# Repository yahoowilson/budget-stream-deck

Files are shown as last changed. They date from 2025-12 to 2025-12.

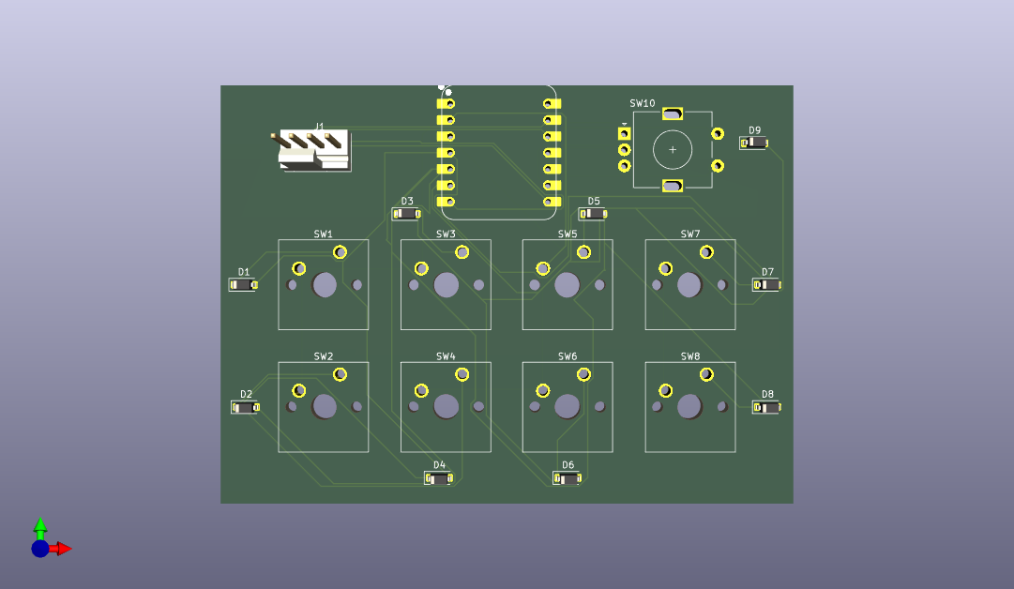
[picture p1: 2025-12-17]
PCB/controller.png

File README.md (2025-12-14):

# Logan's Budget Stream Deck
This is the first custom project that I made entirely myself with blueprint. I wanted a stream deck but did not want to pay $150, so I thought it would be cool to try and make my own. So here is my attempt at a "budget" stream deck with 8 switches, a rotary encoder and an oled screen. all programmable. The BOM is viewable below or downloadable in excel or pdf format to access the links.




entire deck case

Bill of Materials (also in .xlsx or .pdf format above)


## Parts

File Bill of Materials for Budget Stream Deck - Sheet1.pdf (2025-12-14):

Item | Price | Quantity | Shipping Cost | Manufacturer | Total Cost
XIAO RP 2040 | $3.99 | 1 pcs | $6.20 | seeedstudio.com | $10.19
MX Switches | $2.80 | 10 pcs | $4.90 | mechanicalkeyboards.com $7.70
Hotswap Sockets | $1.10 | 10 pcs | $0.00 | mechanicalkeyboards.com $1.10
Blank Keycaps | $7.00 | 8 pcs | $0.00 | mechanicalkeyboards.com $7.00
Diodes | $4.95 | 100pcs | $0.00 | adafruit.com | $4.95
Rotary Encoder with Dial knob$5.70 | | 1 pcs | $5.42 | adafruit.com | $11.12
OLED display | $6.99 | 1 pcs | $0.00 | amazon.com | $6.99
1x4 pin header | $6.99 | 1 pcs | $0.00 | amazon.com | $6.99
PCB | $2 | 1pcs | $5.30 | JLCPCB.com | $5
| $41.52 | | $21.82 | | 61.04

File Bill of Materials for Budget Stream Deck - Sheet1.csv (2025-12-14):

Item | Price | Quantity | Shipping Cost | Manufacturer | Total Cost
XIAO RP 2040 | $3.99 | 1 pcs | $6.20 | seeedstudio.com | $10.19 | x
MX Switches | $2.80 | 10 pcs | $4.90 | mechanicalkeyboards.com | $7.70 | x
Hotswap Sockets | $1.10 | 10 pcs | $0.00 | mechanicalkeyboards.com | $1.10 | x
Blank Keycaps | $5.95 | 8 pcs | $0.00 | mechanicalkeyboards.com | $5.95 | x
Diodes | $4.95 | 100pcs | $0.00 | adafruit.com | $4.95 | x
Rotary Encoder with Dial knob | $5.70 | 1 pcs | $5.42 | adafruit.com | $11.12 | x
OLED display | $6.99 | 1 pcs | $6.99 | amazon.com | $6.99 | x
1x4 pin header | $11.99 | 1 pcs | 0 | amazon.com | $11.99 | x
PCB | $2 | 1pcs | $5.30 | JLCPCB.com | $5 | x
 | $45.47 |  | $28.81 |  | $74.28

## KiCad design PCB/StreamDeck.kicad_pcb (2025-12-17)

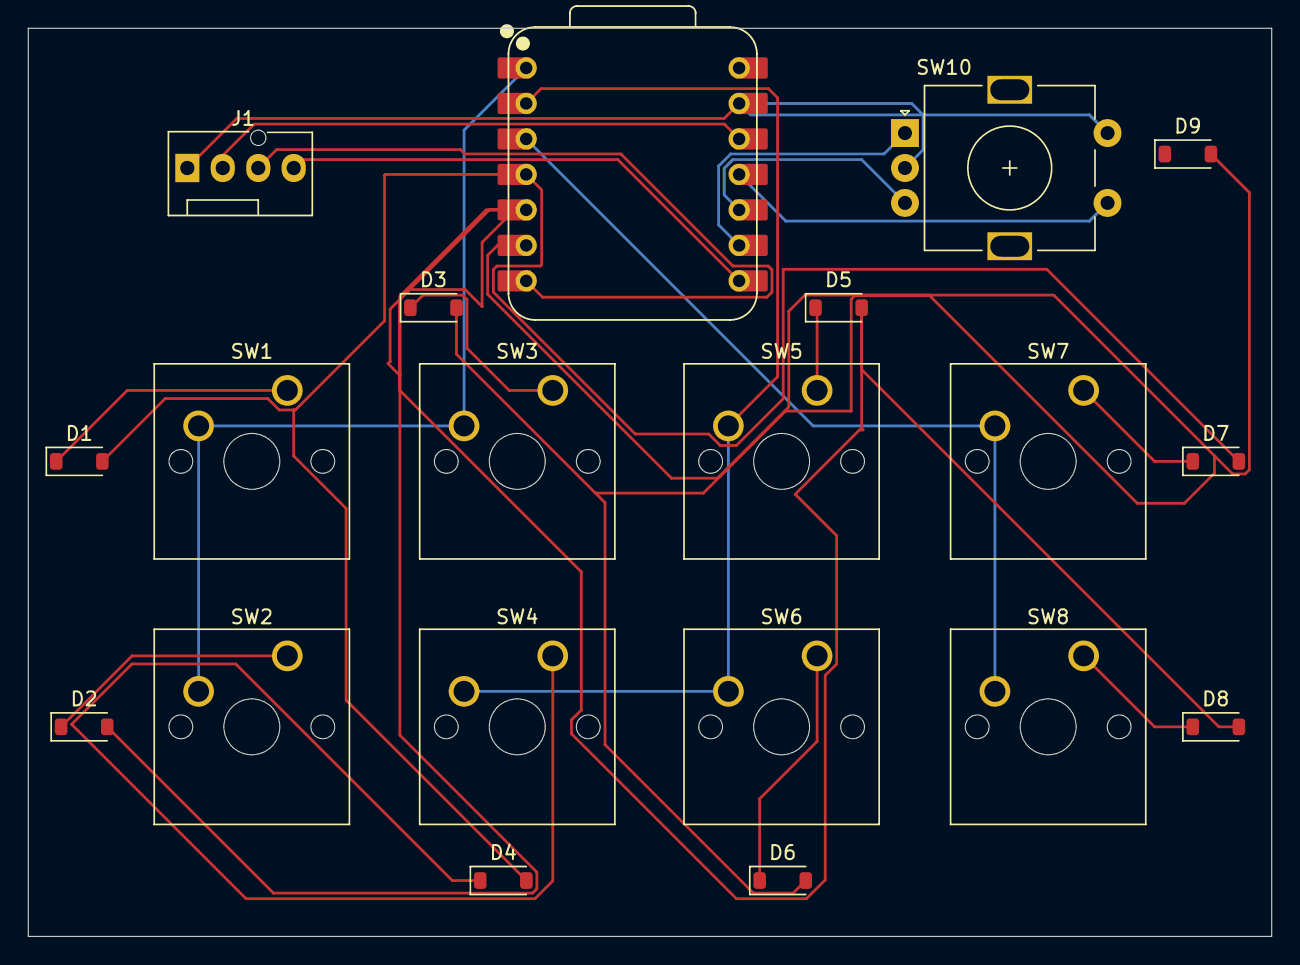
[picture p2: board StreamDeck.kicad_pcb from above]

Board: 2 copper layers, 89.0 x 65.0 mm, 20 parts (0 on the bottom side), 21 nets.

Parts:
D1, D2, D3, D4, D5, D6, D7, D8, D9: D_Small; D_SOD-123
J1: Conn_01x04; FanPinHeader_1x04_P2.54mm_Vertical
SW1, SW2, SW3, SW4, SW5, SW6, SW7, SW8: SW_Push; SW_Cherry_MX_1.00u_PCB
SW10: RotaryEncoder_Switch; RotaryEncoder_Alps_EC11E-Switch_Vertical_H20mm
U1: XIAO-ESP32-C3-DIP; XIAO-ESP32C3-DIP

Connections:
+3.3V: J1.2, U1.12 (VCC_3V3)
/COL0: D1.2 (A), D4.2 (A), D7.2 (A), U1.4 (GPIO5/A3/D3)
/COL1: D2.2 (A), D5.2 (A), D8.2 (A), U1.5 (GPIO6/D4/SDA)
/COL2: D3.2 (A), D6.2 (A), D9.2 (A), U1.6 (GPIO7/D5/SCL)
/ENC_A: SW10.A, U1.9 (GPIO8/D8/SCK)
/ENC_B: SW10.B, U1.10 (GPIO9/D9/MISO)
/ENC_SW: SW10.S1, U1.11 (GPIO10/D10/MOSI)
/ROW0: SW1.2, SW2.2, SW3.2, U1.1 (GPIO2/A0/D0)
/ROW1: SW4.2, SW5.2, SW6.2, U1.2 (GPIO3/A1/D1)
/ROW2: SW7.2, SW8.2, U1.3 (GPIO4/A2/D2)
/SCL: J1.3, U1.7 (GPIO21/D6/TX)
/SDA: J1.4, U1.8 (GPIO20/D7/RX)
GND: J1.1, SW10.C, SW10.S2, U1.13 (GND)
unnamed: D1.1 (K), SW1.1
unnamed: D2.1 (K), SW2.1
unnamed: D3.1 (K), SW3.1
unnamed: D4.1 (K), SW4.1
unnamed: D5.1 (K), SW5.1
unnamed: D6.1 (K), SW6.1
unnamed: D7.1 (K), SW7.1
unnamed: D8.1 (K), SW8.1

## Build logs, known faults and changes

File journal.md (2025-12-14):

Fixed Case and Imported 3D models into Fusion

First, I had to fix the case (again) because the hole for the xiao was not big enough, so I had to modify both the top and bottom until they matched up, next I imported 3d models for the xiao, mx switches, keycaps, the oled and the rotary encoder. This took me a minute because I am still an amateur to Fusion and I hate having to line everything up properly, but I eventually got it all to line up and came out with this. I also created the firmware for the entire device which is found in my repo on github.

Screen Shot 2025-12-13 at 7.25.49 PM
Screen Shot 2025-12-13 at 7.26.11 PM
entire deck case

lmwilson1214 lmwilson1214 added to the journal 2 days ago (2.0 hours)
Created bottom case / Fixed top case

First, I had to fix the top case because all of the dimensions were too small and I forgot too account for the edges that had to connect the top and the bottom. Then, I started the bottom case and made it pretty similar to the hackpad case because i liked the design of that one in particular. I then had to also account for the oled screen and rotary encoder that I had almost completely forgotten about. This took me a while to figure out for some reason.
Screen Shot 2025-12-11 at 8.43.44 PMScreen Shot 2025-12-11 at 8.43.35 PM

lmwilson1214 lmwilson1214 added to the journal 2 days ago (1.5 hours)
Created the top case

I have created the top case for the deck. I know that the OLED may not look centered, and that is because it is not, that is just the place that I would like it to be in.

Screen Shot 2025-12-11 at 7.56.28 PM

lmwilson1214 lmwilson1214 added to the journal 3 days ago (1.5 hours)
Routed PCB / Fixed Schematic

I had to fix a few things on the schematic that were not wired properly, then I put them on a pcb and attempted to route it. It went alright because I am certainty not a professional at this stuff yet. It may be messy, but it works so I'll take it! I will make the case for it in Fusion tomorrow.

Screen Shot 2025-12-10 at 7.54.45 PM

lmwilson1214 lmwilson1214 added to the journal 3 days ago (1.0 hour)
Created Schematic / Added Footprints

I created the schematic with 8 switches, a rotary encoder and a oled screen. I tried using labels this time instead of just wiring this time. I used the xiao rp2040 which is the same as the hackpad! It took me a while because this is only my second project.I also added the correct footprints for everything on the schematic and set SW9 to not actually show up on the PCB as it does not need to according to my research, below is an image of the schematic

Screen Shot 2025-12-10 at 7.51.01 PM

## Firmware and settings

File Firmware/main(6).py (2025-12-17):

# main.py
# ESP32-C3 Wi-Fi Spotify Controller (OLED + Buttons + Encoder)
# Target: Seeed Studio XIAO ESP32-C3

import time
import board
import digitalio
import wifi
import socketpool
import adafruit_requests
import busio
from rotaryio import IncrementalEncoder
import adafruit_ssd1306

# =========================
# USER CONFIG (FILLED IN)
# =========================

WIFI_SSID = "JLJBW"
WIFI_PASSWORD = "Wilsonfam1428!"

# ---- PIN MAP ----
BUTTON_PINS = [
    board.GP2,
    board.GP3,
    board.GP4,
    board.GP5,
    board.GP6,
    board.GP7,
    board.GP8,
    board.GP9,
]

ENC_A = board.GP8
ENC_B = board.GP9
ENC_SW = board.GP10

I2C_SCL = board.GP21
I2C_SDA = board.GP20

# =========================
# SETUP
# =========================

# Buttons
buttons = []
for p in BUTTON_PINS:
    b = digitalio.DigitalInOut(p)
    b.direction = digitalio.Direction.INPUT
    b.pull = digitalio.Pull.UP
    buttons.append(b)

# Encoder
encoder = IncrementalEncoder(ENC_A, ENC_B)
last_position = encoder.position

enc_sw = digitalio.DigitalInOut(ENC_SW)
enc_sw.direction = digitalio.Direction.INPUT
enc_sw.pull = digitalio.Pull.UP

# OLED
i2c = busio.I2C(I2C_SCL, I2C_SDA)
oled = adafruit_ssd1306.SSD1306_I2C(128, 64, i2c)
oled.fill(0)
oled.text("Spotify Controller", 0, 0, 1)
oled.show()

# Wi-Fi
oled.text("WiFi...", 0, 12, 1)
oled.show()
wifi.radio.connect(WIFI_SSID, WIFI_PASSWORD)
oled.text("Connected", 0, 22, 1)
oled.show()

pool = socketpool.SocketPool(wifi.radio)
requests = adafruit_requests.Session(pool, ssl_context=wifi.radio.ssl_context)

# =========================
# SPOTIFY PLACEHOLDERS
# =========================

def oled_status(msg):
    oled.fill_rect(0, 40, 128, 24, 0)
    oled.text(msg, 0, 40, 1)
    oled.show()

def spotify_play_pause():
    oled_status("Play/Pause")

def spotify_next():
    oled_status("Next")

def spotify_prev():
    oled_status("Prev")

def spotify_vol_up():
    oled_status("Vol +")

def spotify_vol_down():
    oled_status("Vol -")

# =========================
# MAIN LOOP
# =========================

last_btn_states = [b.value for b in buttons]

while True:
    # Buttons
    for i, b in enumerate(buttons):
        if last_btn_states[i] and not b.value:
            if i == 0:
                spotify_play_pause()
            elif i == 1:
                spotify_next()
            elif i == 2:
                spotify_prev()
        last_btn_states[i] = b.value

    # Encoder rotation
    pos = encoder.position
    if pos != last_position:
        if pos > last_position:
            spotify_vol_up()
        else:
            spotify_vol_down()
        last_position = pos

    # Encoder press
    if not enc_sw.value:
        spotify_play_pause()
        time.sleep(0.3)

    time.sleep(0.01)

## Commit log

2025-12-11 added schematic files
    [StreamDeck.kicad_pcb, StreamDeck.kicad_sch]
2025-12-14 added downloadable bom
    [Bill of Materials for Budget Stream Deck.xlsx]
2025-12-14 added case with models
2025-12-17 Visual of the pcb
